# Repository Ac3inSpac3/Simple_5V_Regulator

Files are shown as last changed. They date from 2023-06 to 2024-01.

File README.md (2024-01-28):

# Basic 5V Regulator for Raspberry Pi

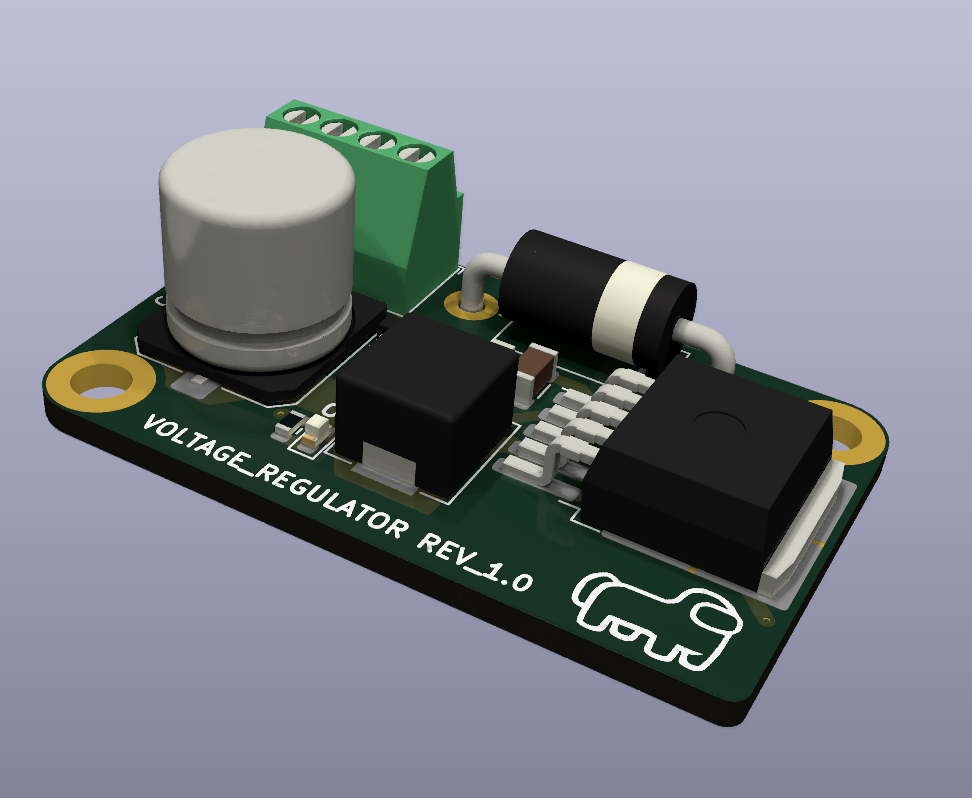
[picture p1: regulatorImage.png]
Regulator Image


## Introduction

This 5V regulator was designed for my EGH419 Class (Mechatronics design 3). It was designed to take the high input voltage the main robot ran off, (a 6s Li-Po drone battery or 4 individual 18650 cells in parallel) and output a consistent 5V for the raspberry pi to run off. The regulator needed to be capable of providing enough current for the Pi to run OpenCV object recognition on top of the navigation code. 

## Features

- Input Voltage: 30V (maximum)
- Output Voltage: 5V
- High Current Output

## Schematic
The schematic for this PCB was designed in KiCAD. KiCAD was used because it is a free program and I do not need to mess around with Educational Licences like I did when working in Altium.
A fuse was implemented into the schematic; however, it was not placed when the PCB was assembled.
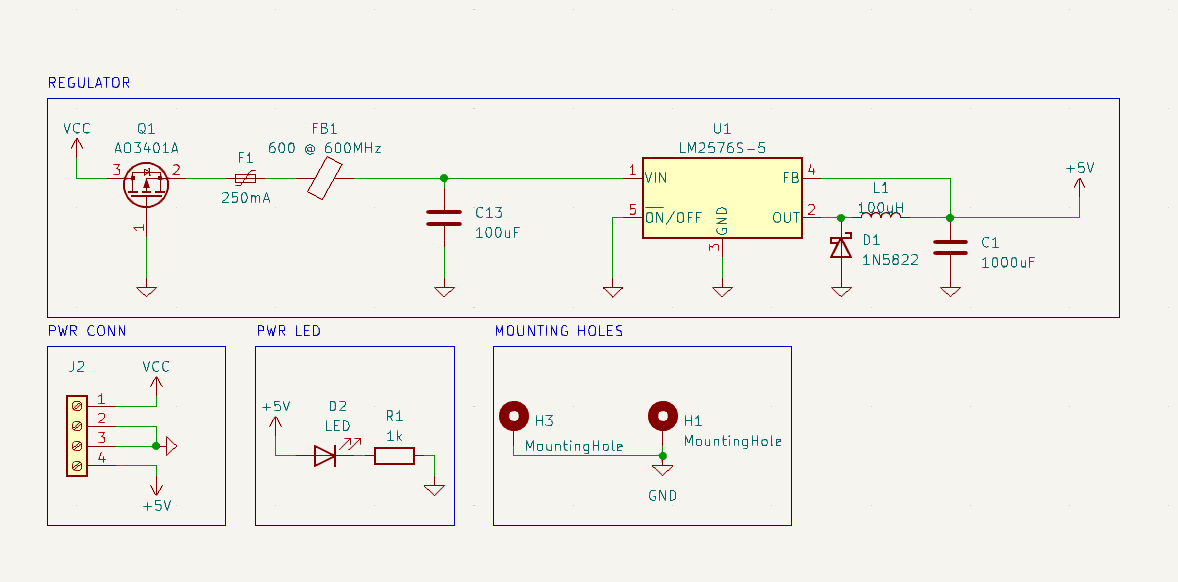
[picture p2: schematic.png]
Schematic


## PCB
The PCB was designed and sent to JLCPCB to be manufactured (Manufacturing and Gerber files provided).
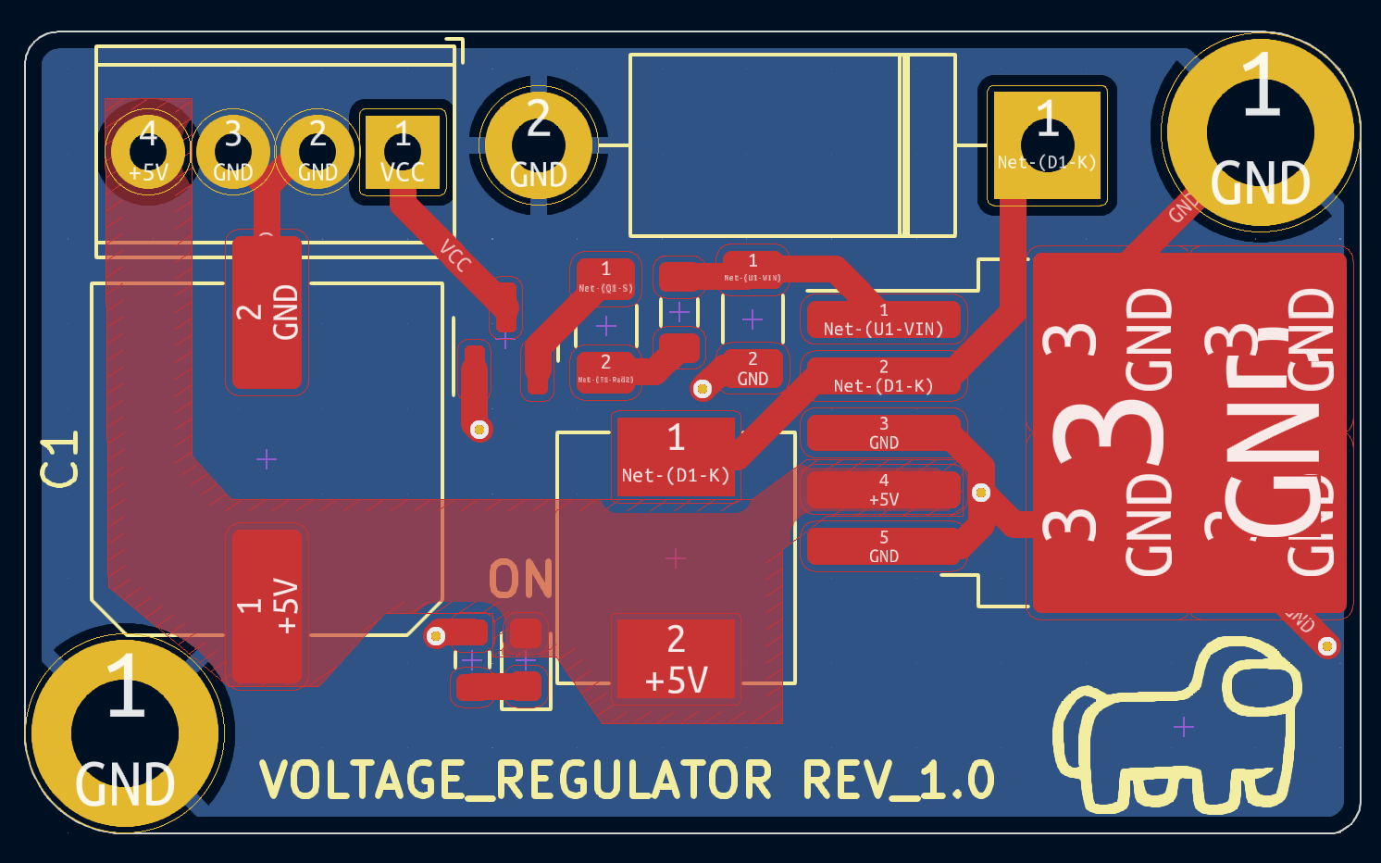
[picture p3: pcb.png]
PCB


## Final Product
With the PCB now manufactured it was tested and placed into the robot. It worked well, providing 5V to the Raspberry Pi without any annoying low power warnings like the previous solution had done.
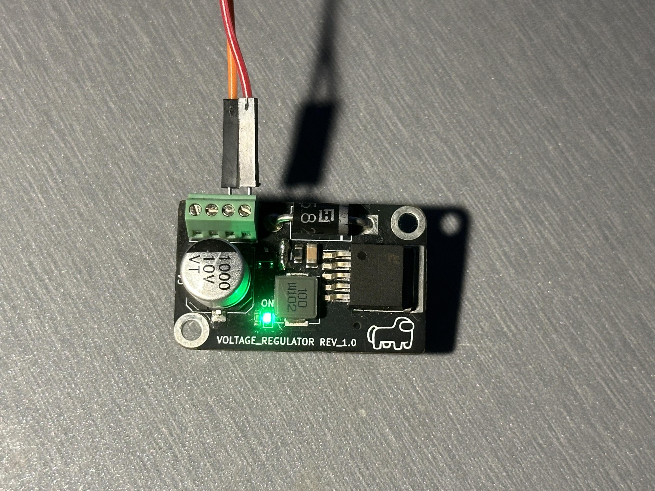
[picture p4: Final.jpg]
Final Product


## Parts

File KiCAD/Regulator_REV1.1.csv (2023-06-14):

Source: | F:\PCB\Regulator\Regulator.kicad_sch
Date: | 6/05/2023 7:41:23 PM
Tool: | Eeschema 7.0.2
Generator: | C:\Program Files\KiCad\7.0\bin\scripting\plugins/bom_csv_grouped_by_value_with_fp.py
Component Count: | 13
Ref | Qnty | Value | Cmp name | Footprint | Description | Vendor | DNP
C1 | 1 | 1000uF | C | Capacitor_SMD:C_Elec_10x10.2 | Unpolarized capacitor
C13 | 1 | 100uF | C | Capacitor_SMD:C_1206_3216Metric | Unpolarized capacitor
D1 | 1 | 1N5822 | 1N5822 | Diode_THT:D_DO-201AD_P15.24mm_Horizontal | 40V 3A Schottky Barrier Rectifier Diode, DO-201AD
D2 | 1 | LED | LED | LED_SMD:LED_0603_1608Metric | Light emitting diode
F1 | 1 | 250mA | Polyfuse_Small | Fuse:Fuse_1206_3216Metric | Resettable fuse, polymeric positive temperature coefficient, small symbol
FB1 | 1 | 600 @ 600MHz | FerriteBead | Inductor_SMD:L_0805_2012Metric | Ferrite bead
H1, H3 | 2 | MountingHole | MountingHole_Pad | MountingHole:MountingHole_3.2mm_M3_DIN965_Pad | Mounting Hole with connection
J2 | 1 | Screw_Terminal_01x04 | Screw_Terminal_01x04 | TerminalBlock_Phoenix:TerminalBlock_Phoenix_MPT-0,5-4-2.54_1x04_P2.54mm_Horizontal | Generic screw terminal, single row, 01x04, script generated (kicad-library-utils/schlib/autogen/connector/)
L1 | 1 | 100uH | L | Inductor_SMD:L_Sunlord_MWSA0605S | Inductor
Q1 | 1 | AO3401A | AO3401A | Package_TO_SOT_SMD:SOT-23 | -4.0A Id, -30V Vds, P-Channel MOSFET, SOT-23
R1 | 1 | 1k | R | Resistor_SMD:R_0603_1608Metric | Resistor
U1 | 1 | LM2576S-5 | LM2576S-5 | Package_TO_SOT_SMD:TO-263-5_TabPin3 | 5V, 3A SIMPLE SWITCHER® Step-Down Voltage Regulator, TO-263

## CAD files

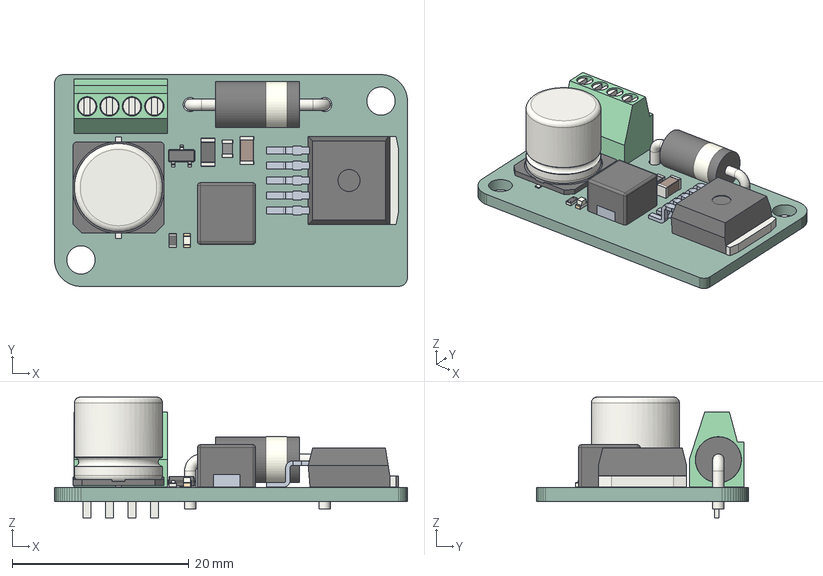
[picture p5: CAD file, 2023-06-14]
KiCAD/Regulator_REV1.1.step
40.0 x 24.0 x 13.7 mm
Regulator PCB

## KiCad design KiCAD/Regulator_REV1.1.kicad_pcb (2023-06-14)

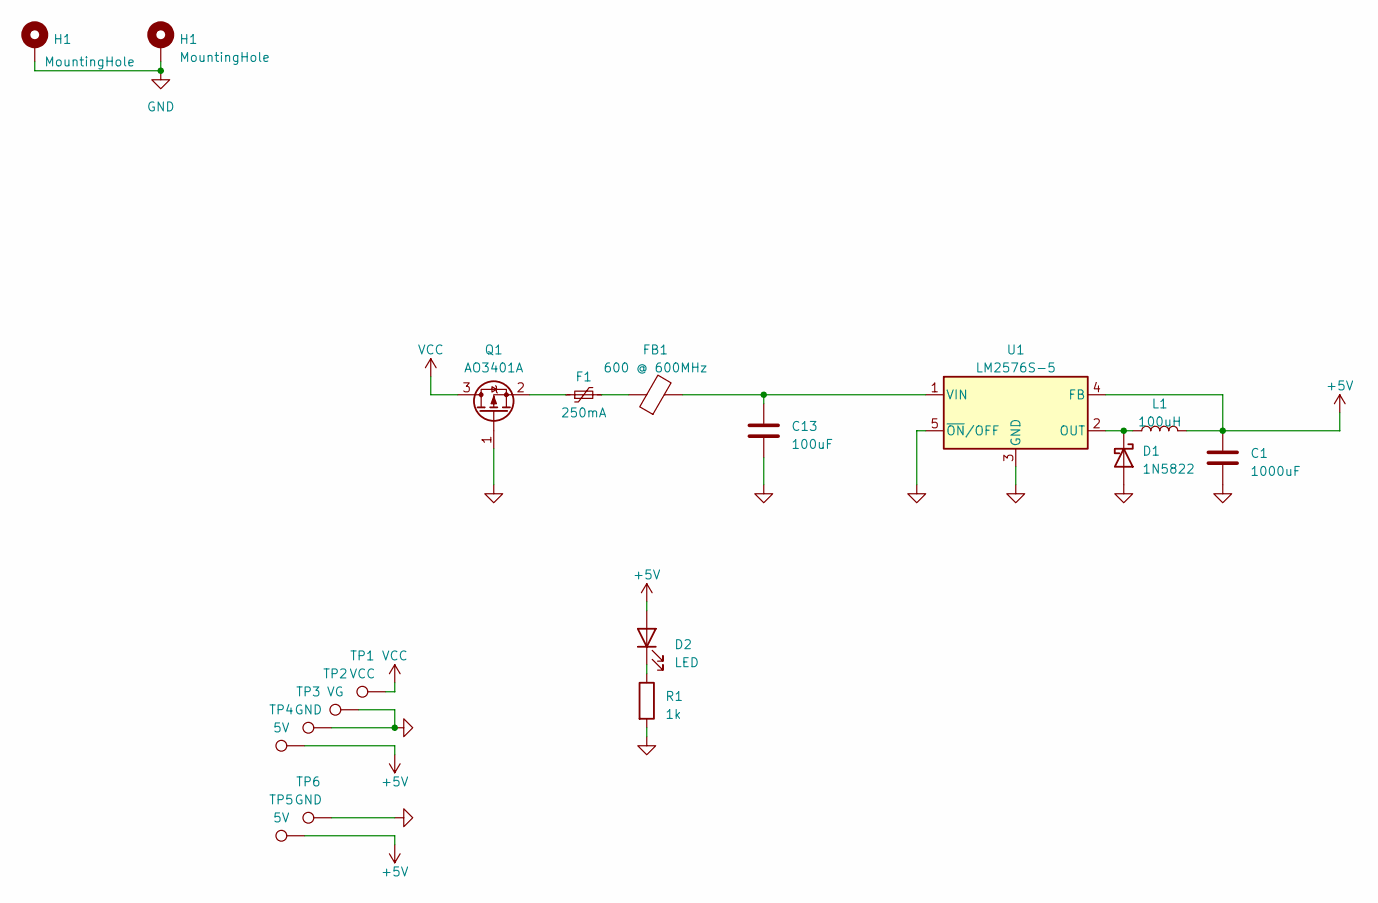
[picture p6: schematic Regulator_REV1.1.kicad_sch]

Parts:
C1: 1000uF; C_Elec_10x10.2
C13: 100uF; C_1206_3216Metric
D1: 1N5822; D_DO-201AD_P15.24mm_Horizontal
D2: LED; LED_0603_1608Metric
F1: 250mA; Fuse_1206_3216Metric
FB1: 600 @ 600MHz; L_0805_2012Metric
H1: MountingHole; MountingHole_3.2mm_M3_DIN965_Pad
L1: 100uH; L_Sunlord_MWSA0605S
Q1: AO3401A; SOT-23
R1: 1k; R_0603_1608Metric
TP1: VCC; TestPoint_Pad_2.0x2.0mm
TP2: VG; TestPoint_Pad_2.0x2.0mm
TP3, TP6: GND; TestPoint_Pad_1.0x1.0mm
TP4, TP5: 5V; TestPoint_Pad_1.0x1.0mm
U1: LM2576S-5; TO-263-5_TabPin3

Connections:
+5V: C1.1, D2.2 (A), L1.2, TP4.1, TP5.1, U1.4 (FB)
GND: C1.2, C13.2, D1.2 (A), H1.1, Q1.1 (G), R1.2, TP2.1, TP3.1, TP6.1, U1.3 (GND), U1.5 (~ON/OFF); also elsewhere on the board
unnamed: D1.1 (K), L1.1, U1.2 (OUT)
unnamed: D2.1 (K), R1.1
unnamed: F1.2, FB1.1
unnamed: F1.1, Q1.2 (S)
unnamed: C13.1, FB1.2, U1.1 (VIN)
VCC: Q1.3 (D), TP1.1

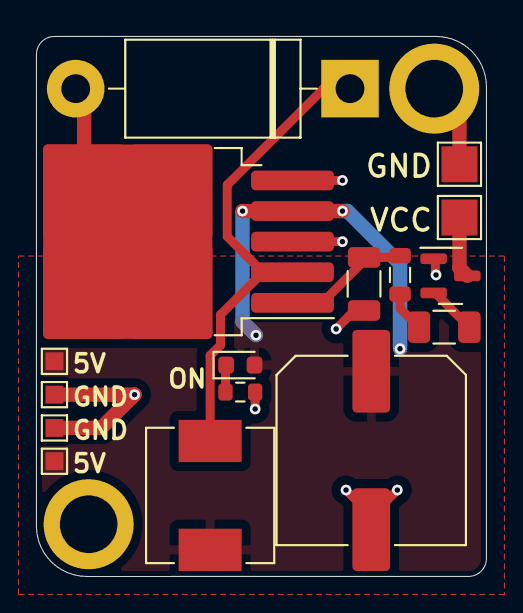
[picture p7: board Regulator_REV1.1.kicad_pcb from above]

Board: 2 copper layers, 25.0 x 30.0 mm, 18 parts (0 on the bottom side), 8 nets.

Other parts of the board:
H3: MountingHole; MountingHole_3.2mm_M3_DIN965_Pad

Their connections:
GND: H3.1; also elsewhere on the board
